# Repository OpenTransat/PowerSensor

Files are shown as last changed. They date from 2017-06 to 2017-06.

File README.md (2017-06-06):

# Power Sensor

* Measures voltage &amp; current of each solar panel separately

* Measures voltage &amp; current of a (backup) battery

* Uses INA219 for measurement

* Communicates via I2C

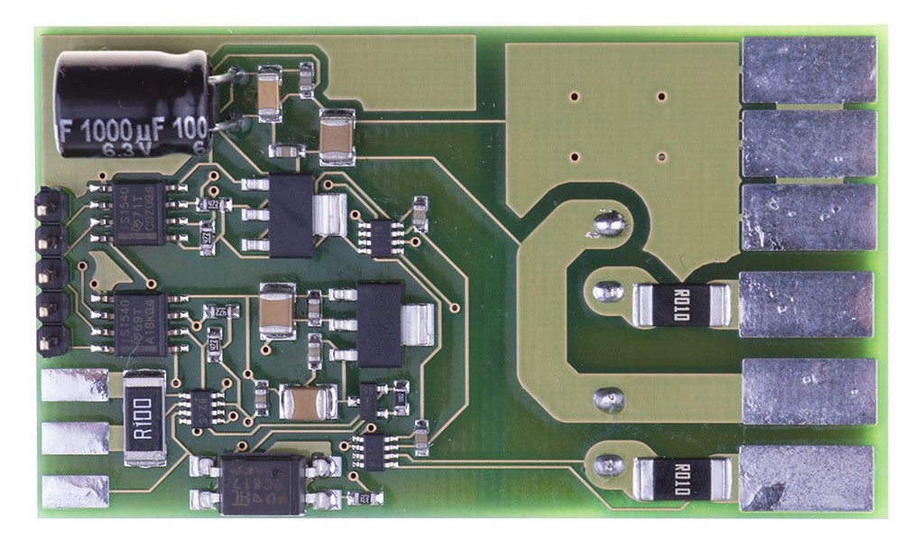
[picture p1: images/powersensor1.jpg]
PowerSensor PCB


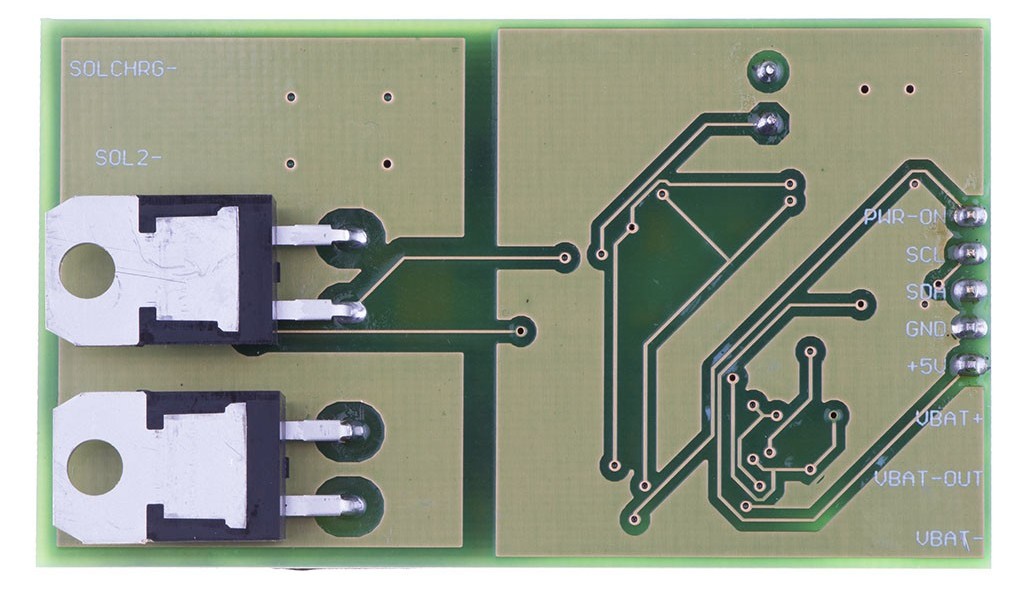
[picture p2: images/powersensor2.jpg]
PowerSensor PCB


There are two thermally isolated regions on the PCB as the Schottky diodes generate heat. The PCB will be potted in a heat conductive epoxy while keeping the regions isolated. The potted Power Sensor will be attached to aluminum structure that will be cooled down by the surrounding water.

## Boat Hardware Scheme

Boat Hardware Scheme

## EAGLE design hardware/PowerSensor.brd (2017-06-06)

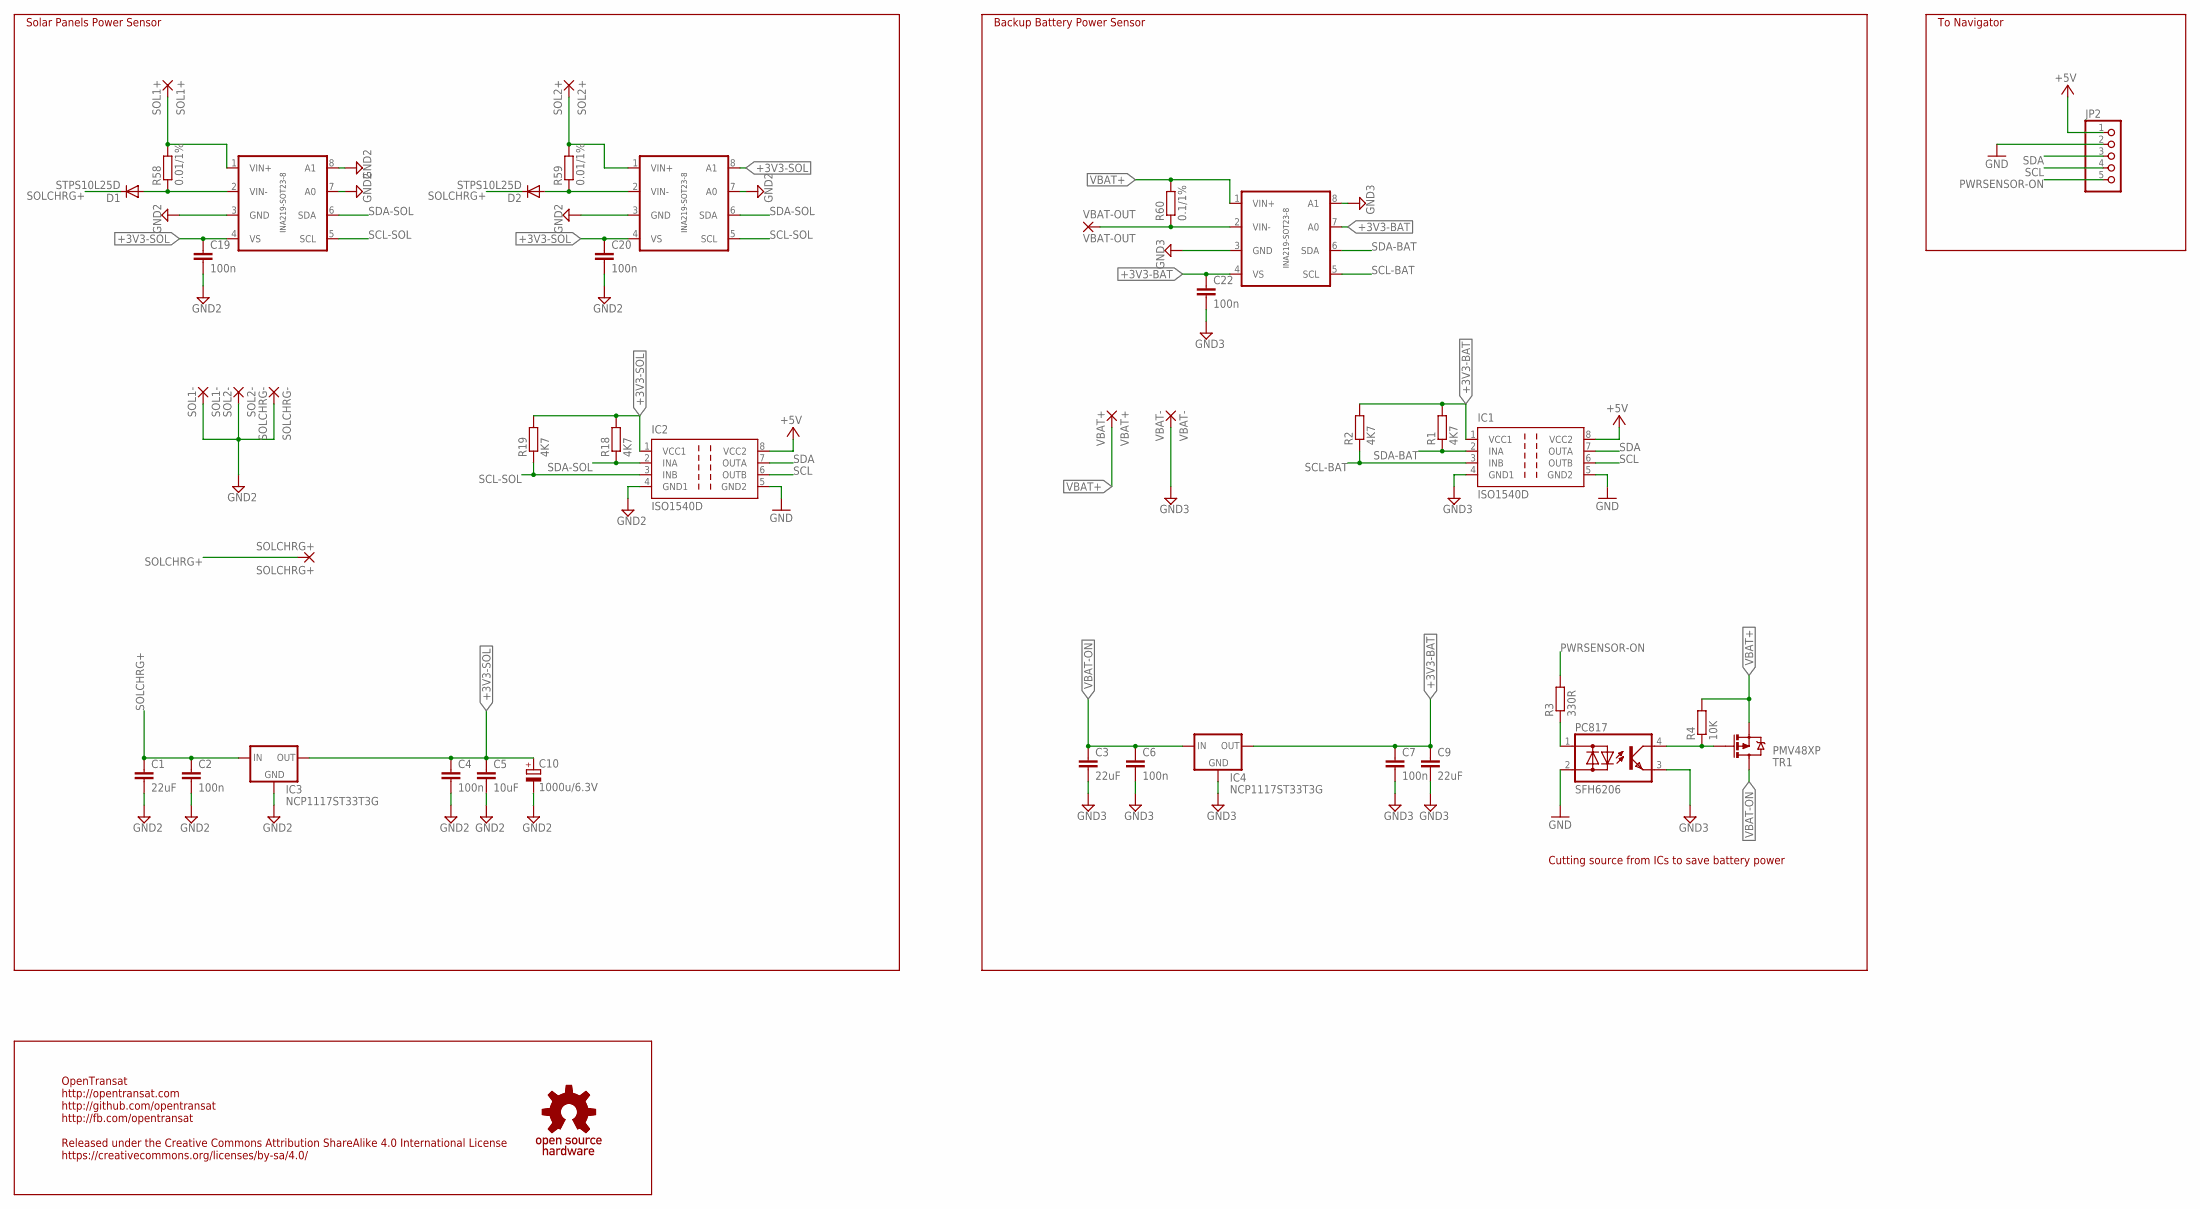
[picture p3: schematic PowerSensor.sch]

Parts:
C1, C3, C9: 22uF; C1210
C2, C4, C6, C7, C19, C20, C22: 100n; C0603
C5: 10uF; C1206
C10: 1000u/6.3V; E3,5-8
D1, D2: STPS10L25D; TO220ACS
IC1, IC2: ISO1540D; SO-08
IC3, IC4: NCP1117ST33T3G; SOT223
JP2: PINHD-1X5; 1X05
PC817: SFH6206; DIL4-SMD
R1, R2, R18, R19: 4K7; R0603
R3: 330R; R0603
R4: 10K; R0603
R58, R59: 0.01/1%; R2512
R60: 0.1/1%; R2512
SOL1+: SOL1+; SMD5,08-10,16
SOL1-: SOL1-; SMD5,08-10,16
SOL2+: SOL2+; SMD5,08-10,16
SOL2-: SOL2-; SMD5,08-10,16
SOLCHRG+: SOLCHRG+; SMD5,08-10,16
SOLCHRG-: SOLCHRG-; SMD5,08-10,16
TR1: PMV48XP; SOT23-3
U$1, U$4, U$5: INA219-SOT23-8; SOT23-8
U$2: OSHW; OSHWM
VBAT+: VBAT+; SMD2,54-5,08
VBAT-: VBAT-; SMD2,54-5,08
VBAT-OUT: VBAT-OUT; SMD2,54-5,08

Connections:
+3V3-BAT: C7.1, C9.1, C22.1, IC1.1 (VCC1), IC4.2 (OUT), IC4.4 (OUT), R1.2, R2.2, U$5.4 (VS), U$5.7 (A0)
+3V3-SOL: C4.1, C5.1, C10.+, C19.1, C20.1, IC2.1 (VCC1), IC3.2 (OUT), IC3.4 (OUT), R18.2, R19.2, U$1.4 (VS), U$4.4 (VS), U$4.8 (A1)
+5V: IC1.8 (VCC2), IC2.8 (VCC2), JP2.1
GND: IC1.5 (GND2), IC2.5 (GND2), JP2.2, PC817.2 (AC2)
GND2: C1.2, C2.2, C4.2, C5.2, C10.-, C19.2, C20.2, IC2.4 (GND1), IC3.1 (GND), SOL1-.1, SOL2-.1, SOLCHRG-.1, U$1.3 (GND), U$1.7 (A0), U$1.8 (A1), U$4.3 (GND), U$4.7 (A0)
GND3: C3.2, C6.2, C7.2, C9.2, C22.2, IC1.4 (GND1), IC4.1 (GND), PC817.3 (E), U$5.3 (GND), U$5.8 (A1), VBAT-.1
unnamed: D1.A, R58.1, U$1.2 (VIN-)
unnamed: D2.A, R59.1, U$4.2 (VIN-)
unnamed: R58.2, SOL1+.1, U$1.1 (VIN+)
unnamed: R59.2, SOL2+.1, U$4.1 (VIN+)
unnamed: R60.1, U$5.2 (VIN-), VBAT-OUT.1
unnamed: PC817.1 (AC1), R3.1
unnamed: PC817.4 (C), R4.1, TR1.1 (G)
PWRSENSOR-ON: JP2.5, R3.2
SCL: IC1.6 (OUTB), IC2.6 (OUTB), JP2.4
SCL-BAT: IC1.3 (INB), R2.1, U$5.5 (SCL)
SCL-SOL: IC2.3 (INB), R19.1, U$1.5 (SCL), U$4.5 (SCL)
SDA: IC1.7 (OUTA), IC2.7 (OUTA), JP2.3
SDA-BAT: IC1.2 (INA), R1.1, U$5.6 (SDA)
SDA-SOL: IC2.2 (INA), R18.1, U$1.6 (SDA), U$4.6 (SDA)
SOLCHRG+: C1.1, C2.1, D1.C, D2.C, IC3.3 (IN), SOLCHRG+.1
VBAT+: R4.2, R60.2, TR1.2 (S), U$5.1 (VIN+), VBAT+.1
VBAT-ON: C3.1, C6.1, IC4.3 (IN), TR1.3 (D)

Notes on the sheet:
Solar Panels Power Sensor
Backup Battery Power Sensor
To Navigator
OpenTransat http://opentransat.com http://github.com/opentransat http://fb.com/opentransat Released under the Creative Commons Attribution ShareAlike 4.0 International License https://creativecommons.org/licenses/by-sa/4.0/
Cutting source from ICs to save battery power

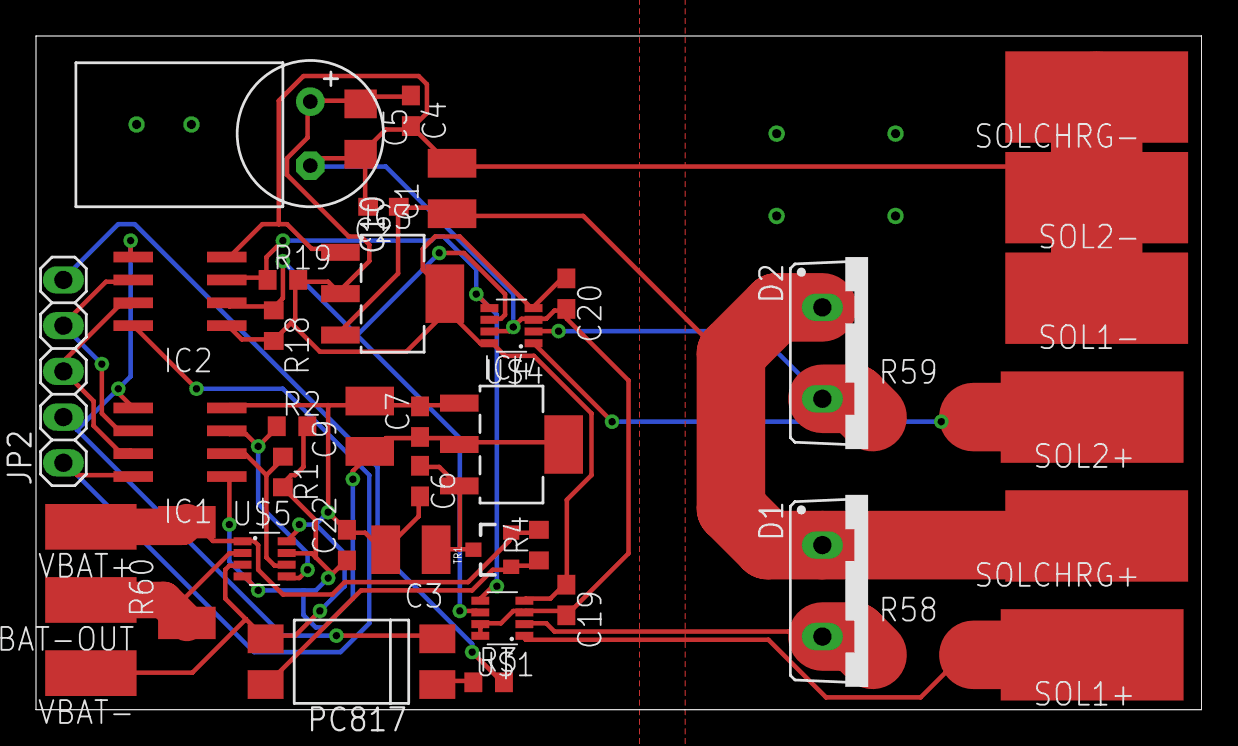
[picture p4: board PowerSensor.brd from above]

Board: 2 copper layers, 64.8 x 37.4 mm, 43 parts (0 on the bottom side), 23 nets.
